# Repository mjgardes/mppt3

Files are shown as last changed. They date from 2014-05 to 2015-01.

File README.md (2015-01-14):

mppt3
=====
Software and hardware designs for DC-DC power conversion with max power point tracking and lots of other cool features for PV applications.

Software runs on a Beaglebone Black.  The goal is to have up to three analog boards stack on top of that.  Although the way I'm driving the boards now, I could go up to eight. Maybe eleven if I figure out how to build kernel modules.  Each analog module would be optimizing one panel to eke out every last possible mW.

My goal was to have this somewhat working by July '14.

See the wiki for current progress

If you have suggestions or feature requests or whatever, I'm all ears.  Or even if you find a product out there that does this better.

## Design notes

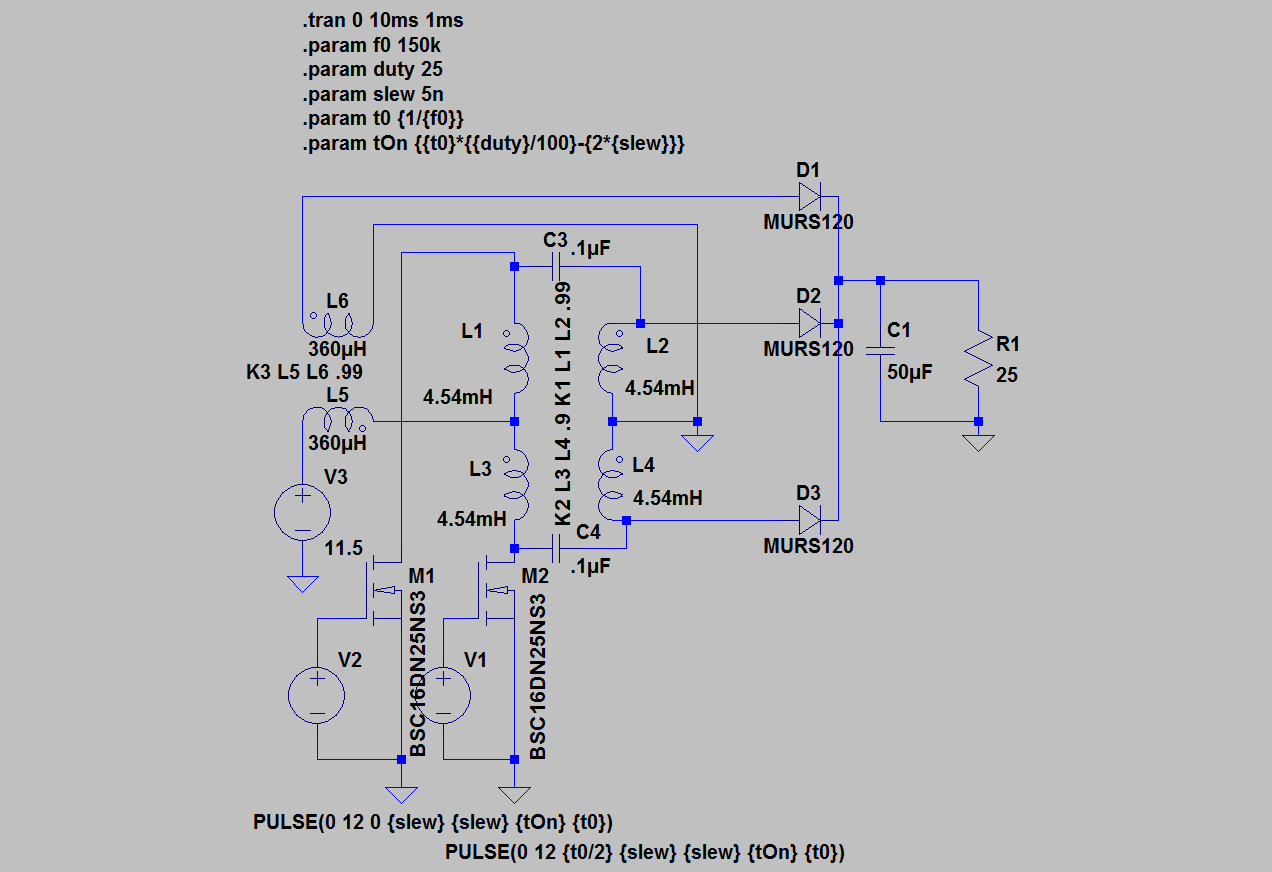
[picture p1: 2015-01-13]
weinberg.png

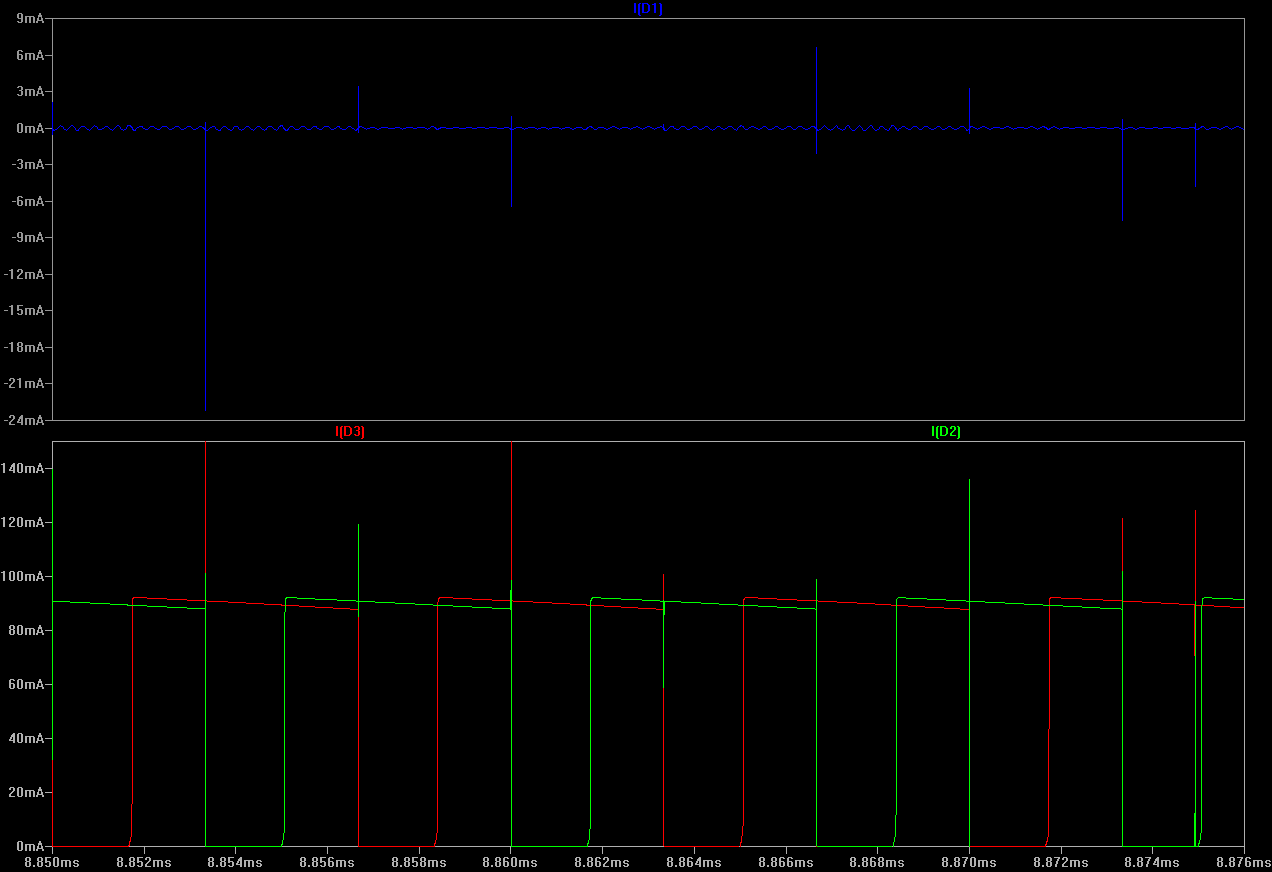
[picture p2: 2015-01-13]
flyback.png

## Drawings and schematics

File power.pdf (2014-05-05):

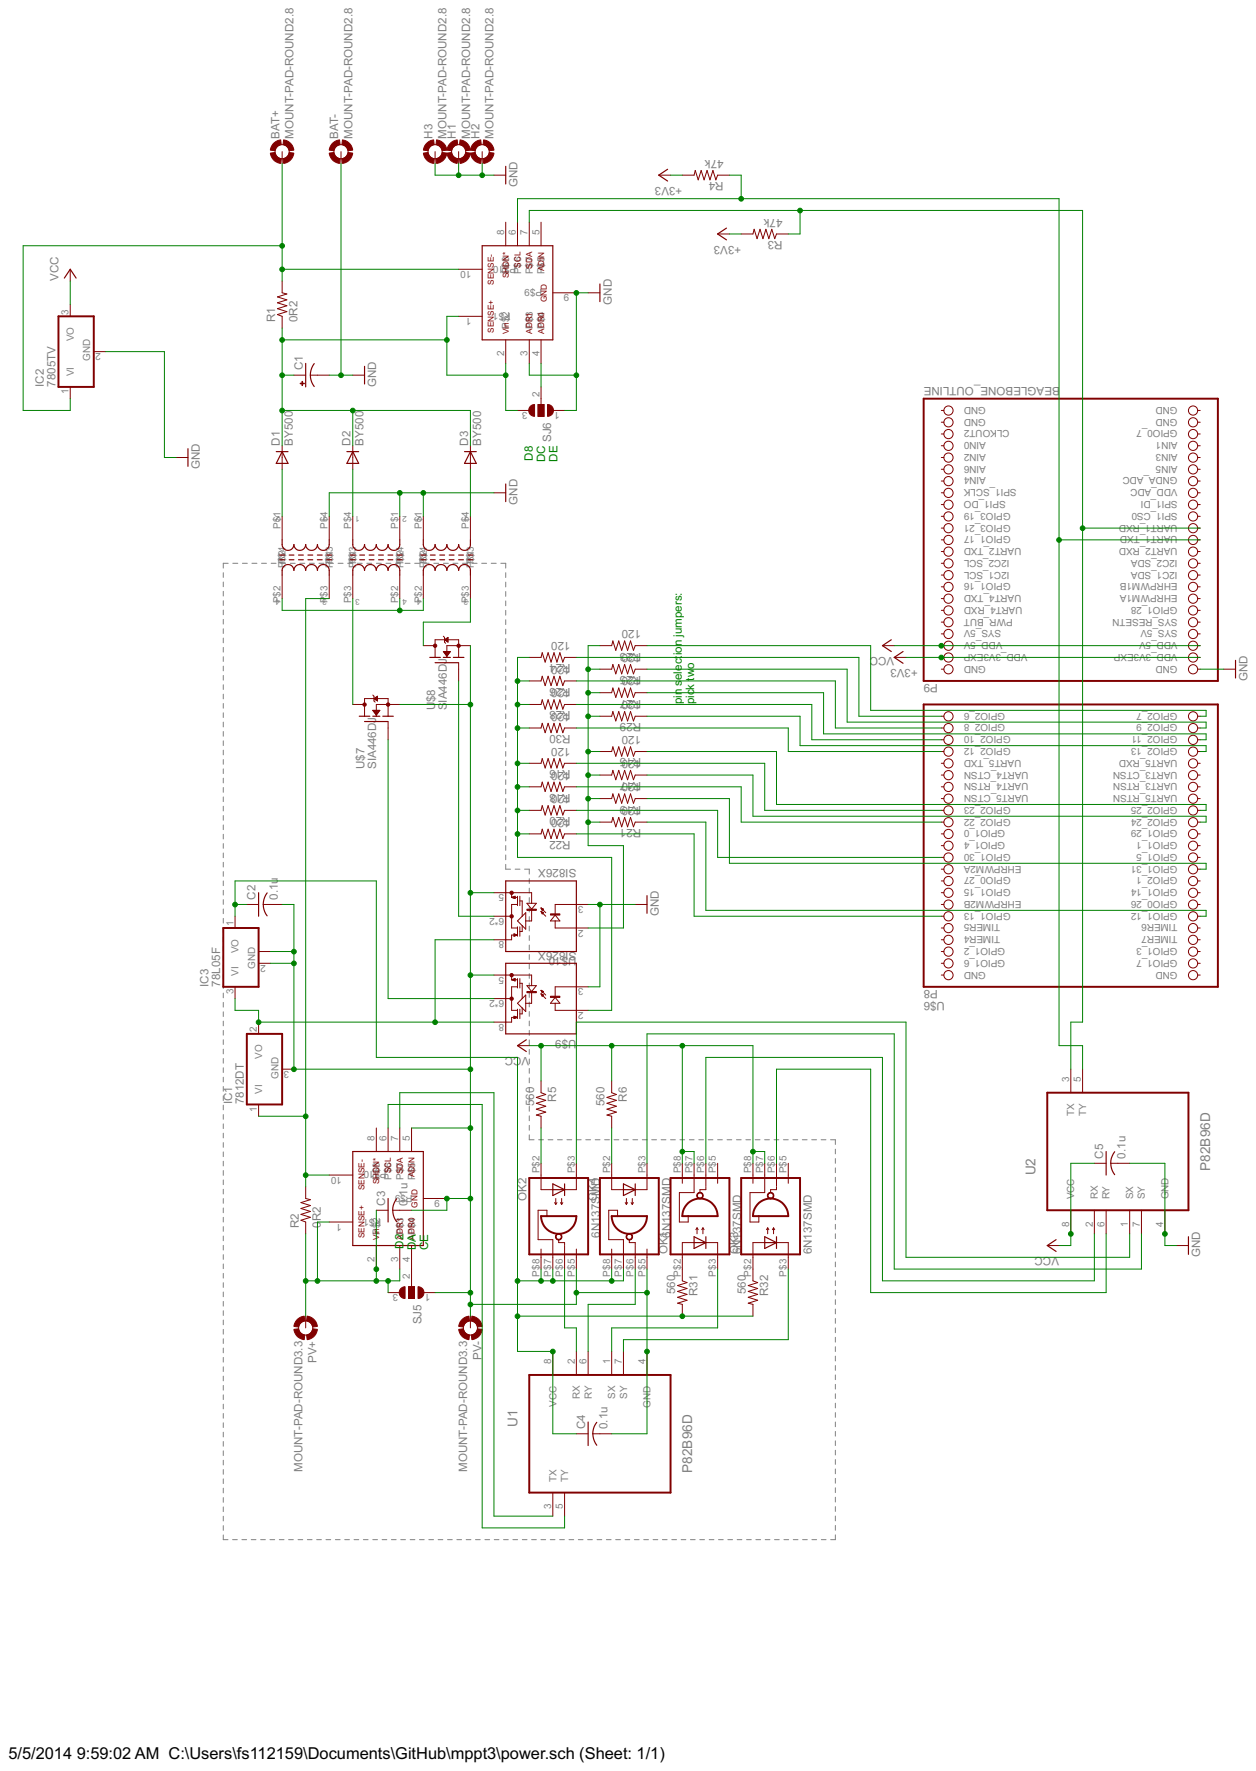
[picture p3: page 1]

SENSE- SENSE+ Vin ADR1 ADR0 GND

pin selection jumpers: pick two

5/5/2014 9:59:02 AM C:\Users\fs112159\Documents\GitHub\mppt3\power.sch (Sheet: 1/1)

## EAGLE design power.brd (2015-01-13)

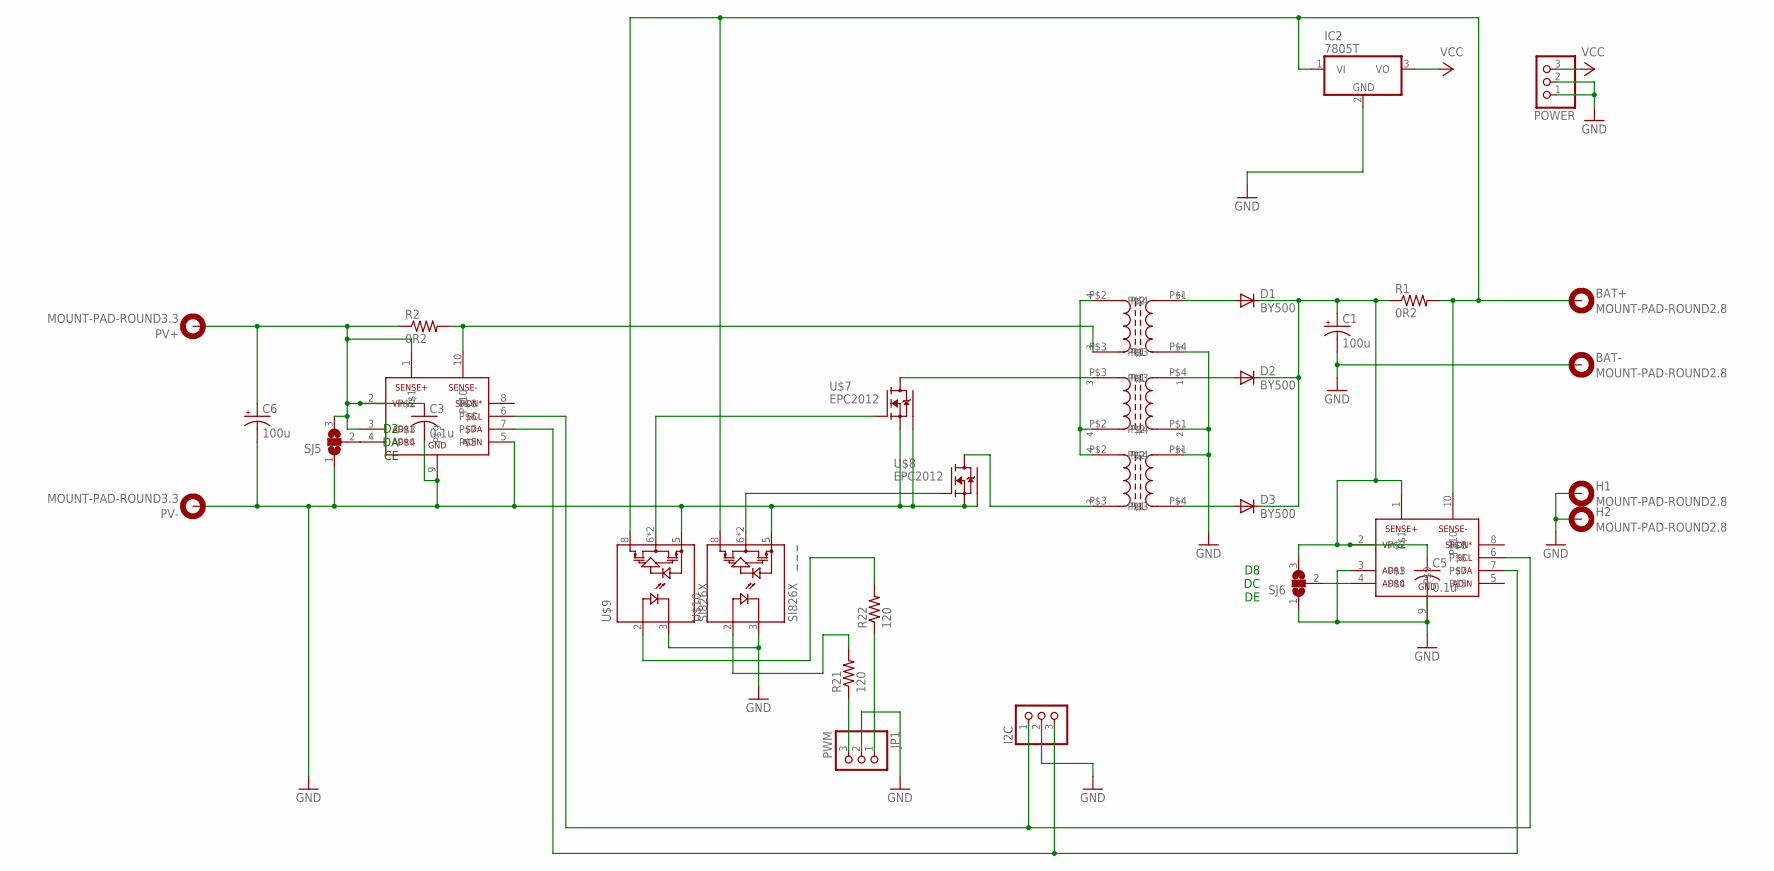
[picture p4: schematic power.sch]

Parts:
BAT+: MOUNT-PAD-ROUND2.8; 2,8-PAD
BAT-: MOUNT-PAD-ROUND2.8; 2,8-PAD
C1, C6: 100u; E5-10,5
C3, C5: 0.1u; C0603K
D1, D2, D3: BY500; DO201-15
H1, H2: MOUNT-PAD-ROUND2.8; 2,8-PAD
I2C: PINHD-1X3; 1X03
IC2: 7805T; TO220H
JP1: PWM; 1X03
POWER: PINHD-1X3; 1X03
PV+: MOUNT-PAD-ROUND3.3; 3,3-PAD
PV-: MOUNT-PAD-ROUND3.3; 3,3-PAD
R1, R2: 0R2; R1206
R21, R22: 120; R0603
SJ5, SJ6: SJ2W; SJ_2
U$1, U$2: LTC4151; MSOP10
U$3: PLH10AN2211R5P2B; L10-13
U$4, U$5: TLF14CBH3321R0K1; L13-17
U$7, U$8: EPC2012; EGAN-DIE-7
U$9, U$10: SI826X; SO08

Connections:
GND: BAT-.B2,8, C1.-, C3.2, C5.2, C6.-, H1.B2,8, H2.B2,8, I2C.2, IC2.2 (GND), JP1.2, POWER.1, POWER.2, PV-.B3,3, SJ5.1, SJ6.1, U$1.5, U$1.9, U$2.3, U$2.9, U$3.P$4, U$4.P$1, U$5.P$1, U$7.SOURCE (S), U$7.SUBSTRATE, U$8.SOURCE (S), U$8.SUBSTRATE, U$9.3 (GND1), U$9.5 (GND2), U$10.3 (GND1), U$10.5 (GND2)
unnamed: U$3.P$2, U$4.P$2, U$5.P$2
unnamed: U$5.P$3, U$7.DRAIN (D)
unnamed: U$4.P$3, U$8.DRAIN (D)
unnamed: BAT+.B2,8, IC2.1 (VI), R1.2, U$2.10, U$9.8 (VDD2), U$10.8 (VDD2)
unnamed: D3.A, U$4.P$4
unnamed: R21.2, U$10.2 (VI)
unnamed: D2.A, U$5.P$4
unnamed: SJ5.2, U$1.4
unnamed: C1.+, C5.1, D1.C, D2.C, D3.C, R1.1, SJ6.3, U$2.1, U$2.2
unnamed: U$8.GATE (G), U$10.6 (VO), U$10.7 (VO)
unnamed: D1.A, U$3.P$1
unnamed: U$7.GATE (G), U$9.6 (VO), U$9.7 (VO)
unnamed: SJ6.2, U$2.4
unnamed: JP1.3, R21.1
unnamed: JP1.1, R22.1
unnamed: R22.2, U$9.2 (VI)
PV: C3.1, C6.+, PV+.B3,3, R2.1, SJ5.3, U$1.1, U$1.2, U$1.3
PVIN: R2.2, U$1.10, U$3.P$3
SCL: I2C.1, U$1.6, U$2.6
SDA: I2C.3, U$1.7, U$2.7
VCC: IC2.3 (VO), POWER.3

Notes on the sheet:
D2 DA CE
D8 DC DE

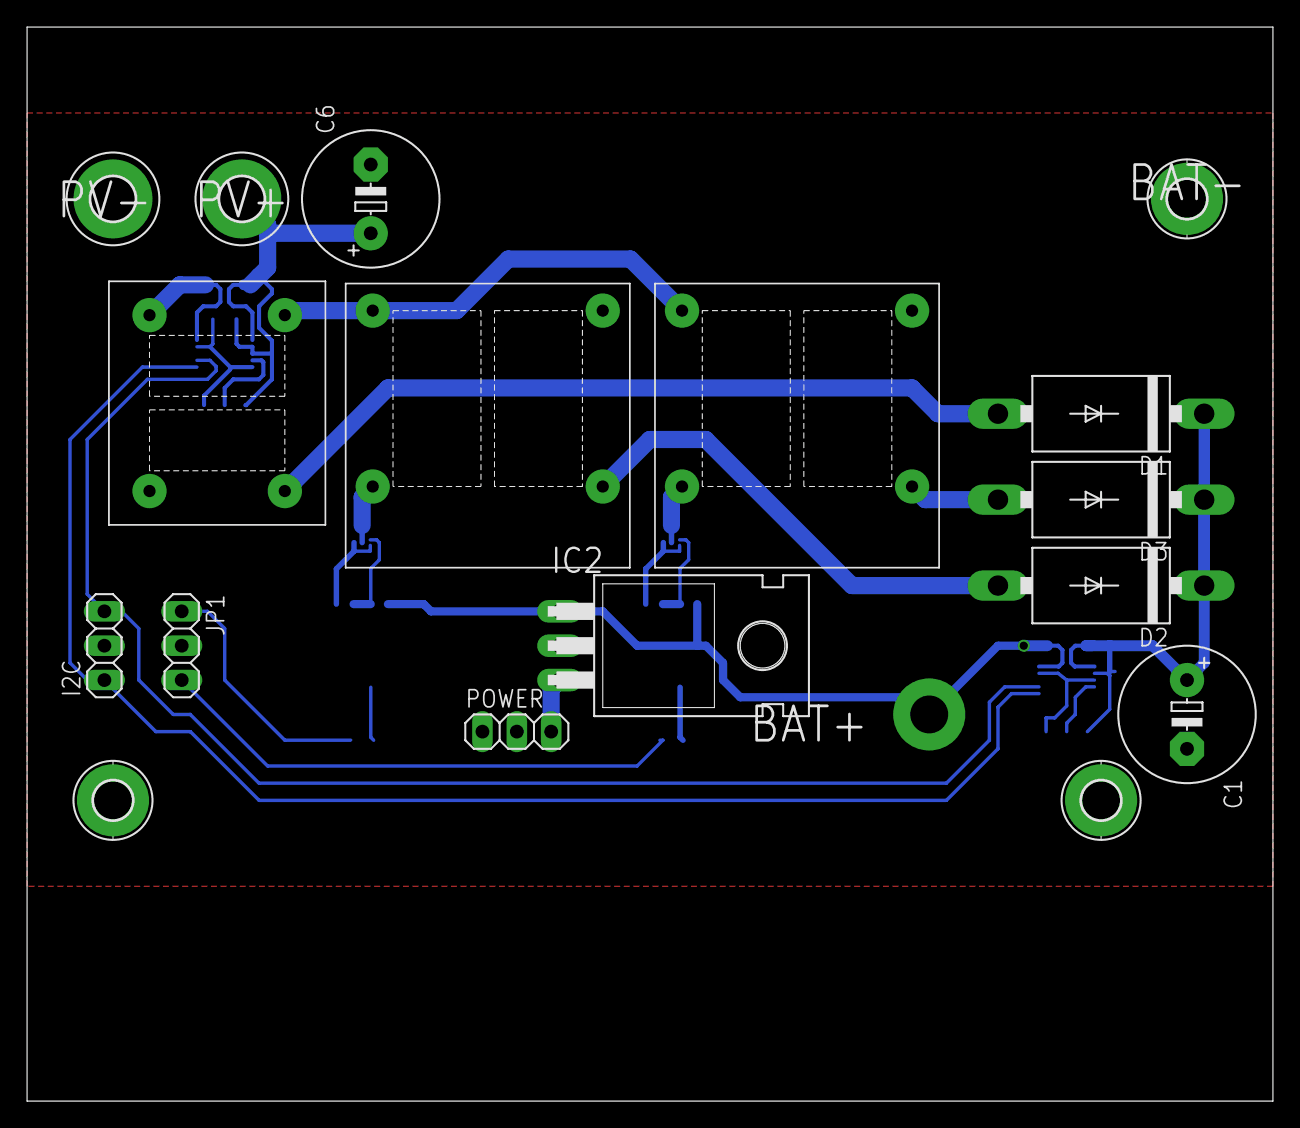
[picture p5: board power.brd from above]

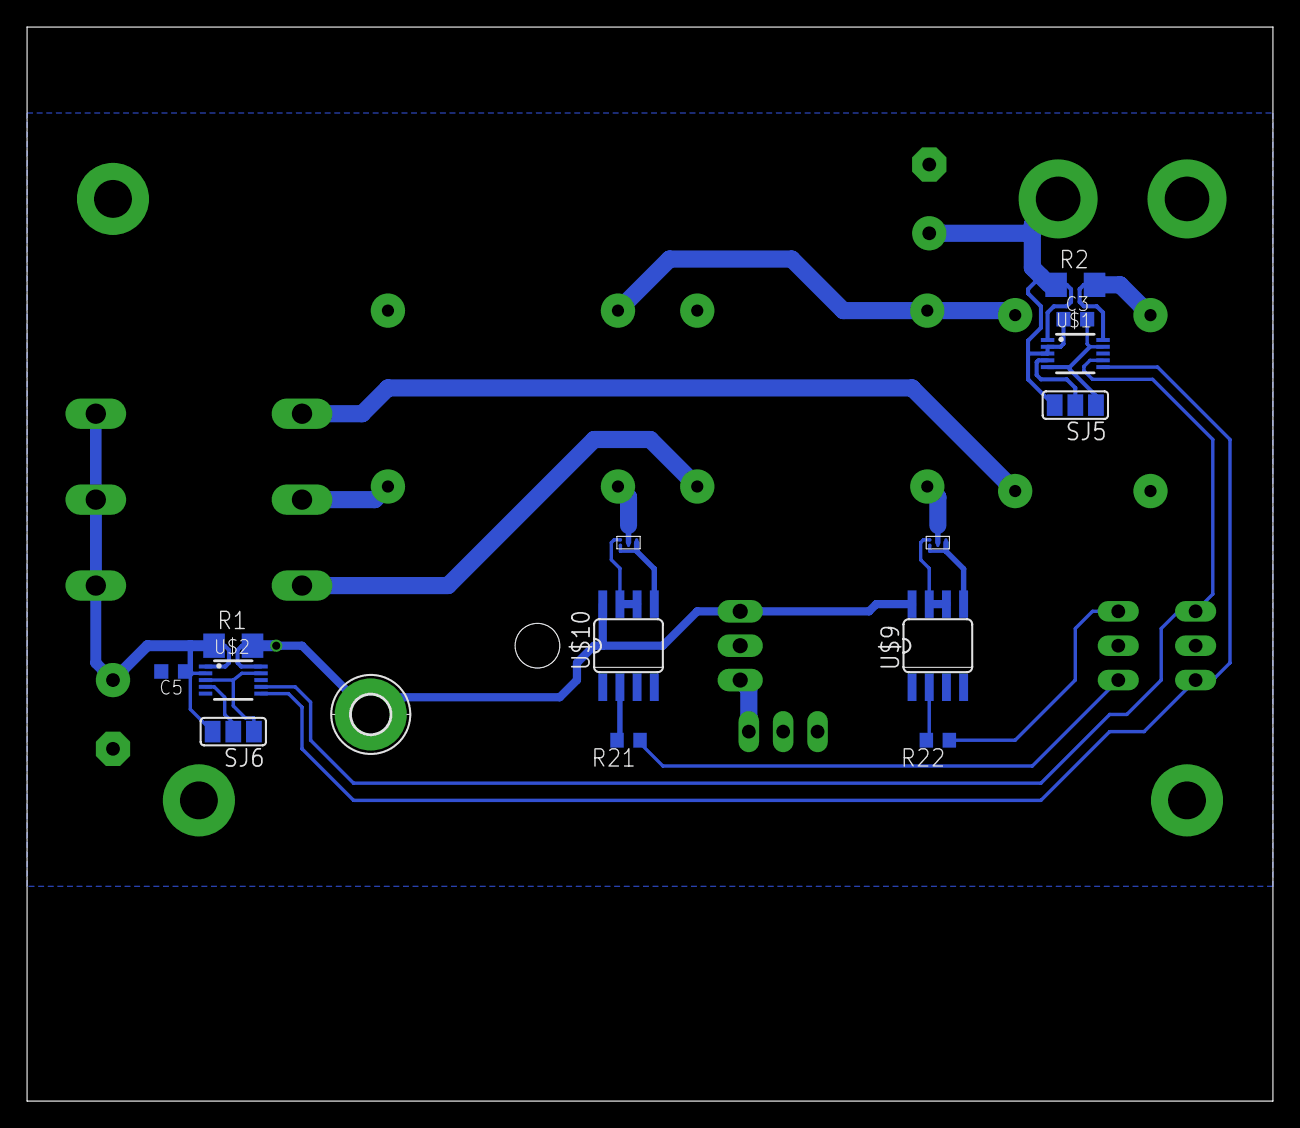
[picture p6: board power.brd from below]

Board: 2 copper layers, 92.1 x 79.4 mm, 32 parts (15 on the bottom side), 22 nets.

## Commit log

2014-03-04 hacking things together
    [power.brd, power.sch]
2014-03-04 Transformer footprints and really awful looking board routing
    Pretty sure at least one of the transformers is wired in the wrong way
    too
    [power.brd, power.sch]
2014-03-05 little tweaks
    [power.brd]
2014-03-06 fiddling with the layout
    [power.brd]
2014-03-06 proposed beaglebone connections and resistor dividers
    [power.brd, power.sch]
2014-03-06 change all the things
    [power.brd, power.sch]
2014-03-06 schematic might be correct. board is routed. no idea if it's routed well.
    [power.brd, power.sch]
2014-03-06 better ground paths
    [power.brd, power.sch]
2014-03-07 fixed a lot of things. confidence that this could work is up to 1%.
    [power.brd, power.sch]
2014-03-07 I'm starting to like this layout. Not sure why.
    [power.brd, power.sch]
2014-03-09 built a prototype, characterized it, and realized that i have the transformers swapped around. :(
    [firstdata.ods]
2014-03-10 Corrected choke packages in library
    Rerouted board to reflect library changes
    [power.brd, power.sch]
2014-03-17 Tried to make a device tree overlay
2014-03-17 Analog GND
    This might be important.
    [power.brd, power.sch]
2014-03-17 broken device tree. just making a backup. move along, nothing to see here.
2014-03-18 some board fixes
    [power.brd, power.sch]
2014-03-18 device tree overlay seems to work for the PWM part. use the analog helper for now until i feel like pasting it in.
2014-03-18 more board and schematic fixes. added slightly negative voltage reference hack.
    [power.brd, power.sch]
2014-03-20 back to the drawing board, i guess
2014-03-25 made things more complicated, fixed a schematic mistake, added gate drivers
    [power.brd, power.sch]
2014-03-25 fixed more things, probably broke more things in the process
    [power.brd, power.sch]
2014-03-25 fixed more things that had been bothering me.
    [power.brd, power.sch]
2014-03-26 Schematic cleanup
    Thanks, Roger!
    [power.brd, power.sch]
2014-03-26 Fixed the schematic, rerouted the board
    [power.brd, power.sch]
2014-04-06 did you try reversing the polarity?
    [power.brd]
2014-04-16 wait for the next one...
    [power.brd, power.sch]
2014-04-22 Removing all the failed ideas
    Everything may be broken
    [power.brd, power.sch]
2014-04-29 added LTC4151 I2C IV monotors to the schematic and some other fixes. The prototype doesn't work yet, so watch out.
    [power.brd, power.sch]
2014-04-30 don't worry, it's not as bad as it looks
    [power.brd, power.sch]
2014-04-30 still working on it
    [power.brd, power.sch]
2014-04-30 almost there
    [power.brd, power.sch]
2014-04-30 need a snapshot here
    [power.brd, power.sch]
2014-04-30 LETS HOOK UP THE MOSFETS THE RIGHT WAY, OKAY?
    [power.brd, power.sch]
2014-04-30 i'm pretty sure i had the FETs in the right way in the first place, actually...
    [power.brd, power.sch]
2014-05-04 circuit rework in progress
    [power.brd, power.sch]
2014-05-05 more optoisolation
    [power.brd, power.sch]
2014-05-05 still more things to fix
    [power.brd, power.sch]
2014-05-05 board should be okay
    [power.brd]
2014-05-05 sending out for another prototype
    [power.brd, power.sch]
2014-05-05 PDF of schematic
2014-05-05 fixed labels
    [power.brd, power.sch]
2014-05-05 input capacitor? might help.
    [power.brd, power.sch]
2014-05-05 sent out to board fab
2014-05-29 important fixes... and that 7812 that isn't actually a 7812 is still a problem
    [power.brd, power.sch]
2014-05-30 ****ing pinouts
    [power.brd, power.sch]
2014-05-30 found more mistakes in the isolated i2c bus
    [power.brd, power.sch]
2014-06-06 7-bit i2c addresses to reduce confusion
    [LTC4151-address-bits.ods]
2014-06-06 Cluttering up the schematic some more
    [power.brd, power.sch]
2014-07-24 Pulled the hard stuff out of the schematic Still needs some work and a board redo
    [power.brd, power.sch]
2014-07-25 Snapshotting here before changing things a lot
    [power.brd, power.sch]
2014-10-30 Redid the board. Simplified everything and switched to GaN FETs.
    [power.brd, power.sch]
2015-01-13 board revamp and LTspice schematic
    [power.brd, power.sch]
